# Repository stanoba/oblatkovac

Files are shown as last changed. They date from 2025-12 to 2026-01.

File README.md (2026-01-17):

# Electric Wafer Maker Controller (Oblátkovač)

Electric Wafer Maker Controller (Oblátkovač) runs on an Arduino Nano and is built with PlatformIO. It reads a thermistor, accepts input from a rotary encoder, and displays status on an SH1106/SSD1306 monochrome OLED using the U8g2 graphics library.

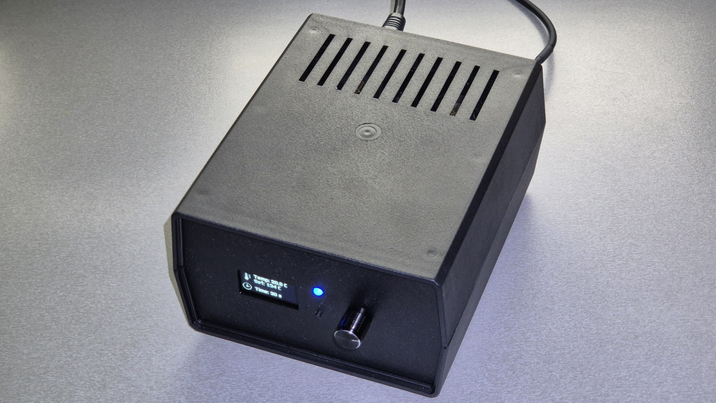
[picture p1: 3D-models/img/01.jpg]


## Software

The firmware source is in [Software](Software/) folder.

Build with PlatformIO, see `platformio.ini` for board environments.

## Bundled libraries

For reproducible builds this repo includes the following libraries under `Software/lib/`:

- `RotaryEncoder-1.5.3` — rotary encoder handling
- `ThermistorLibrary-1.0.6` — thermistor-to-temperature conversion
- `U8g2` — OLED display graphics
- `button-debounce-0.2.1` — simple button debounce helper

See `Software/lib/README` for details about each bundled library.

## Development tips

- If you change pin assignments, update `Software/src/pins.h` and rebuild for your target.
- Use PlatformIO's verbose build (`pio run -v`) to see full compiler/linker output when troubleshooting.
- To add a board environment, edit `platformio.ini` and add matching pin defines in the sketch as needed.

## Hardware

PCB design files are in the [Hardware](Hardware/) folder.

## Enclosure / 3D models

The electronics are housed in a [Z2AW enclosure](https://www.kradex.com.pl/product/enclosures_with_side_panels/z2a?lang=en). 3D-print models are in [3D-models](3D-models/).

## License

Project code is provided as-is. Third-party libraries retain their original licenses — see each library's `LICENSE` file in `Software/lib/`.

## Safety

**Warning:** this project involves mains and high-voltage circuitry. Working on or near high voltage can cause serious injury or death.

- **Disconnect power:** Always remove mains power and verify the circuit is de-energized before touching components.
- **Use PPE:** Wear appropriate personal protective equipment (insulating gloves, eye protection) when testing live systems.
- **Isolation:** Keep a safe distance from exposed conductors; use insulated tools and work on insulated surfaces.
- **Discharge capacitors:** Safely discharge capacitors before servicing; they can hold lethal charge after power removal.
- **One hand rule:** When possible, use the one-hand rule to avoid current passing through the chest.
- **Qualified personnel:** If you are not experienced with mains/high-voltage electronics, seek assistance from a qualified technician or electrician.
- **Work sober and focused:** Never work on high-voltage circuits when tired, impaired, or alone.

Follow local regulations and best practices for electrical safety. The authors are not responsible for damage or injury from misuse.

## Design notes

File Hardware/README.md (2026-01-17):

# Oblátkovač PCB (Work in progress)

The PCB for Oblátkovač (Electric Wafer Maker Controller) and schematic were designed using Autodesk EAGLE. Source EAGLE project files (schematic and board) are included in this folder.

- **Gerbers:** Manufacturing Gerber files are available in the [Hardware/gerber files/](Hardware/gerber%20files/) directory for PCB fabrication.
- **Libraries:** The EAGLE libraries used in the design are included in the [Hardware/libraries/](Hardware/libraries/) folder.
- **Notes:** Open the .sch and .brd files in Autodesk EAGLE. To regenerate Gerbers, use EAGLE's CAM processor and export an RS-274X Gerber set.
</br></br>

Eagle libraries Downloaded from:

- ArduinoNanoV30.lbr
    - https://github.com/psrobotics/eagle_lib
- Rembrandt Electronics - JST XH Connectors v1-0.lbr
    - https://github.com/yann-ygn/eagle-libraries/blob/master/Rembrandt%20Electronics%20-%20JST%20XH%20Connectors%20v1-0.lbr
    - https://www.diymodules.org/eagle-show-object?id=1012211612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
- 13oled.lbr
	- https://github.com/suhail-jr/1.3-OLED-Display-Module-Eagle-Library/
- mastrogippo.lbr
    - https://github.com/mastrogippo/MastroGippo-Eagle-library

## Schematic

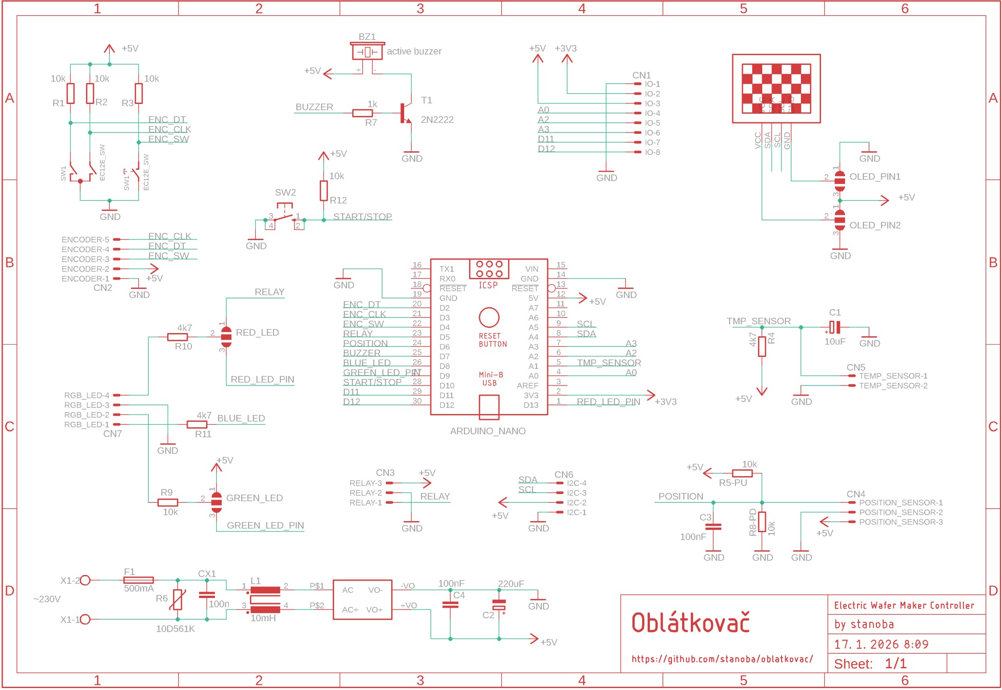
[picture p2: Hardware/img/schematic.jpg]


## PCB

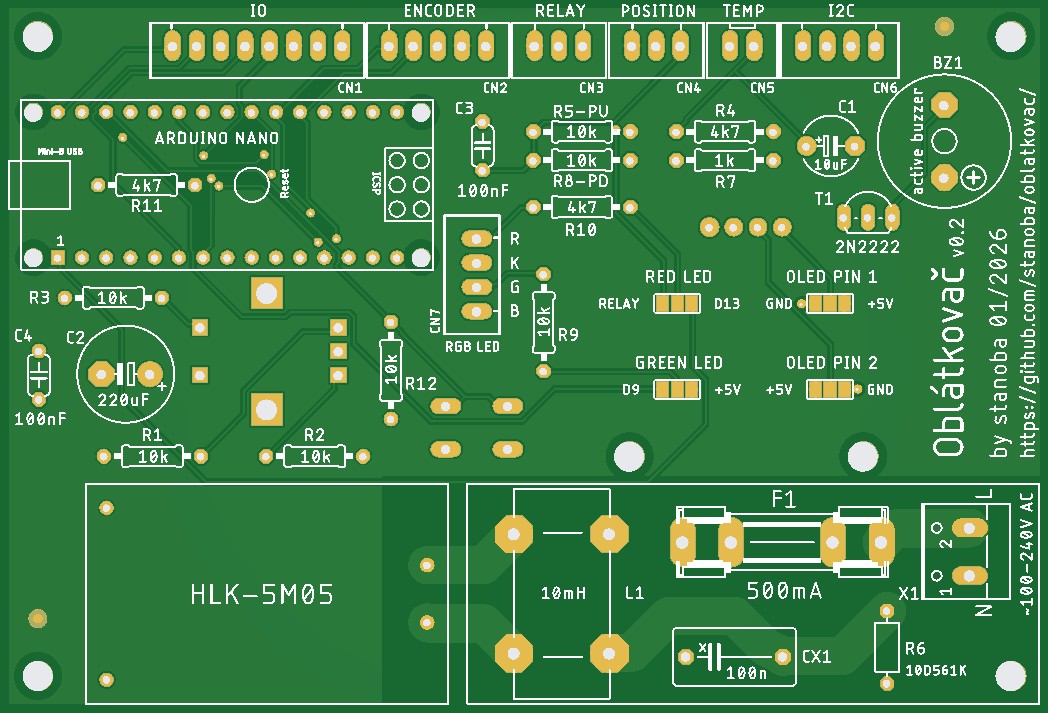
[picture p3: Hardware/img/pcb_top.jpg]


Front side:</br>
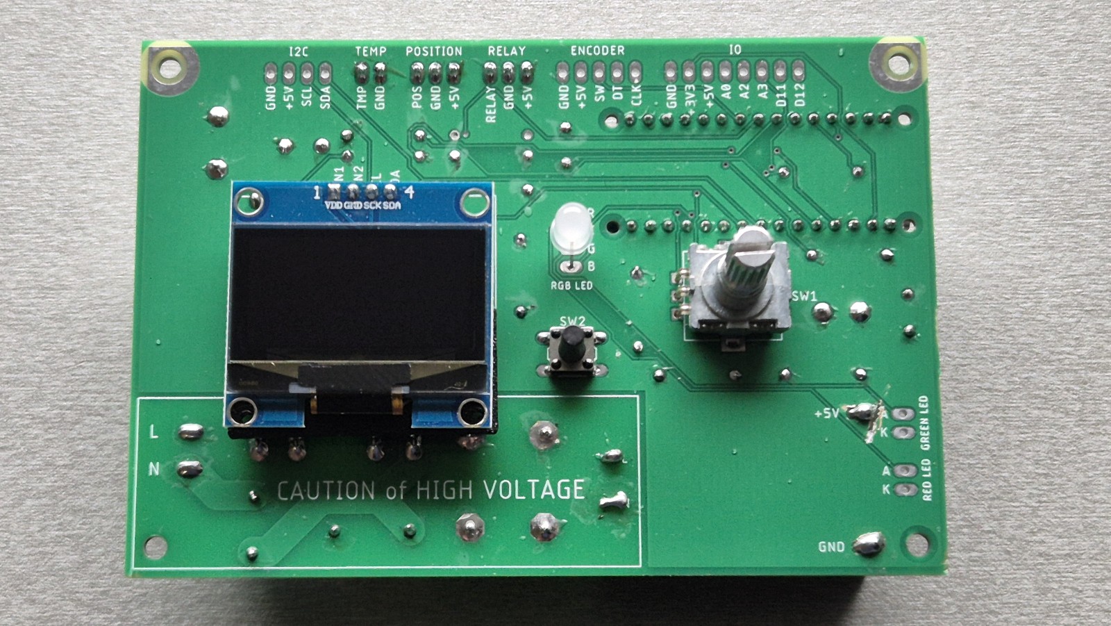
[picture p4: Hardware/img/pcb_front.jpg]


Back side:</br>
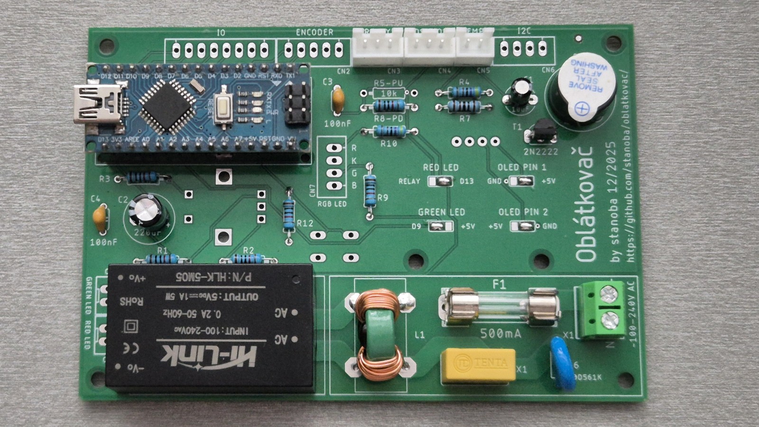
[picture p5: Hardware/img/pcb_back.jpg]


## Safety

**Warning:** this project involves mains and high-voltage circuitry. Working on or near high voltage can cause serious injury or death.

- **Disconnect power:** Always remove mains power and verify the circuit is de-energized before touching components.
- **Use PPE:** Wear appropriate personal protective equipment (insulating gloves, eye protection) when testing live systems.
- **Isolation:** Keep a safe distance from exposed conductors; use insulated tools and work on insulated surfaces.
- **Discharge capacitors:** Safely discharge capacitors before servicing; they can hold lethal charge after power removal.
- **One hand rule:** When possible, use the one-hand rule to avoid current passing through the chest.
- **Qualified personnel:** If you are not experienced with mains/high-voltage electronics, seek assistance from a qualified technician or electrician.
- **Work sober and focused:** Never work on high-voltage circuits when tired, impaired, or alone.

Follow local regulations and best practices for electrical safety. The authors are not responsible for damage or injury from misuse.

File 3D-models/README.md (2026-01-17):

# 3D Models and Enclosure

This folder contains the enclosure design and photos for the Oblátkovač electronics. The electronics fit into a [Z2AW enclosure](https://www.kradex.com.pl/product/enclosures_with_side_panels/z2a?lang=en), front and back panels (faces) are 3D-printed to match the PCB layout and connectors.

## Design source

- Original design created in SketchUp (file: `design.skp`).
- The provided SketchUp file is the editable source for the printed front/back panels and mounting features.

## Included files

- `design.skp` — SketchUp source project for the enclosure panels and mounting features.
- `front_pannel.stl` — Front panel with integrated mounting features for the PCB.
- `back_pannel.stl` — Back panel with cutouts and mounting openings for connectors.
- `heatsink_holder.stl` — Mounting bracket for the SSR (solid-state relay) heat sink.
- `oled_support.stl` — Support/bracket for the OLED display module.

## Printing & export notes

- Print the front and back panels in PETG (recommended) or ABS. PETG is easier to print and more dimensionally stable; ABS offers higher temperature resistance but may require an enclosed printer and additional post-processing.
- Typical print settings: 0.2 mm layer height, 15–30% infill, 2–4 perimeters. Use supports where needed for overhangs.
- Export to STL from SketchUp (SketchUp Pro or STL export plugin). Ensure model units are millimetres and scale is 1:1 before exporting.
- Check fit against the PCB and fasteners; consider printing a small test-fit section before full prints.

## Assembly

- Attach the assembled PCB to the front panel using the integrated mounting bosses.
- Install and secure all connectors into the back panel cutouts.
- Attach the SSR heat sink to its bracket and fasten securely.
- Complete wiring between the PCB, connectors and power components, following the schematic and safety guidelines.

## Final product



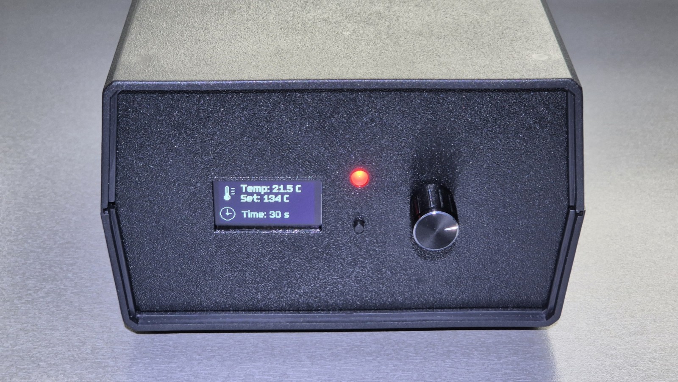
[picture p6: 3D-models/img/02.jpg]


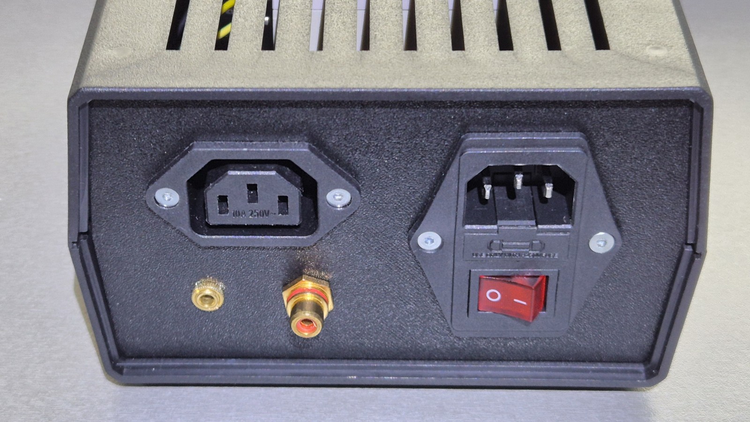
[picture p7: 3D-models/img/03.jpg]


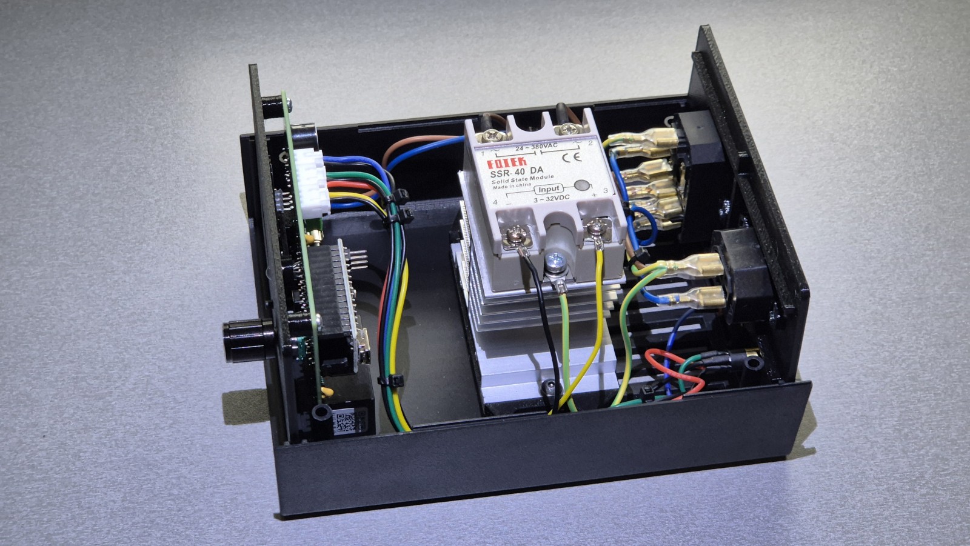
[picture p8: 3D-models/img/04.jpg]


## License

See the repository `LICENSE` at the project root for licensing terms.

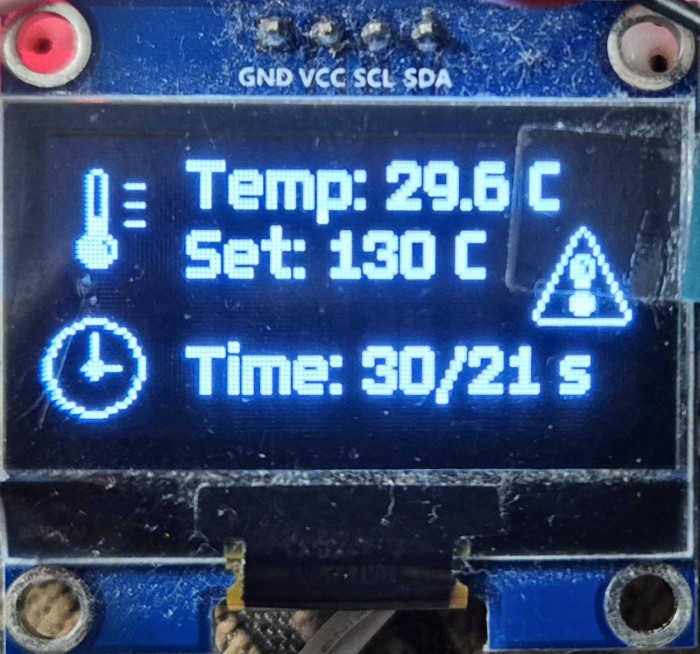
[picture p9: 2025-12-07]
Hardware/img/oled.jpg

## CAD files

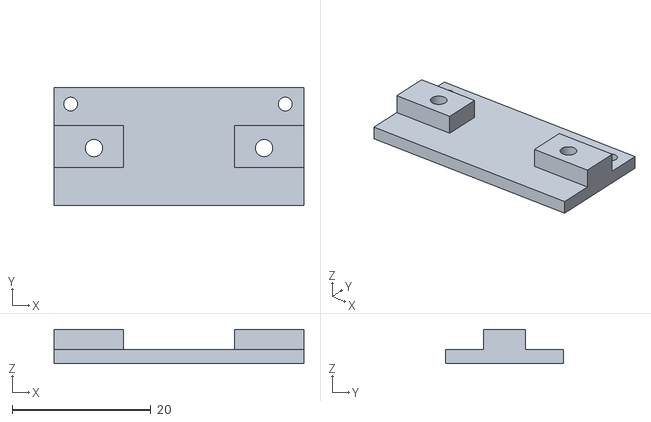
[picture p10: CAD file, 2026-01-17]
3D-models/oled_support.stl
36.0 x 17.0 x 4.90

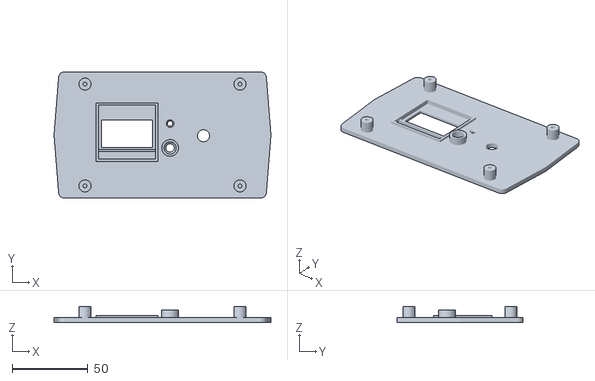
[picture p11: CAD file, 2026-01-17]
3D-models/front_pannel.stl
142.8 x 83.2 x 10.6

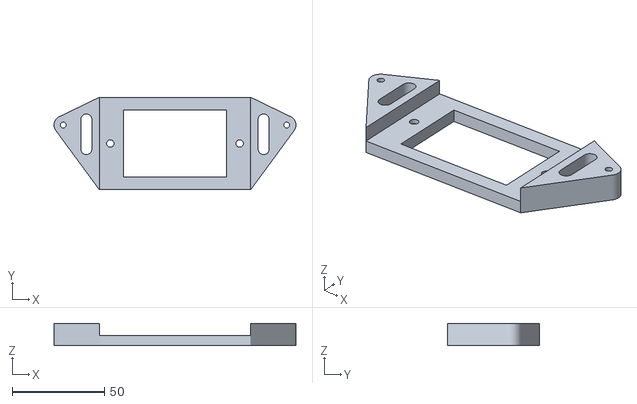
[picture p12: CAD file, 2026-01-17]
3D-models/heatsink_holder.stl
131.0 x 50.0 x 12.0

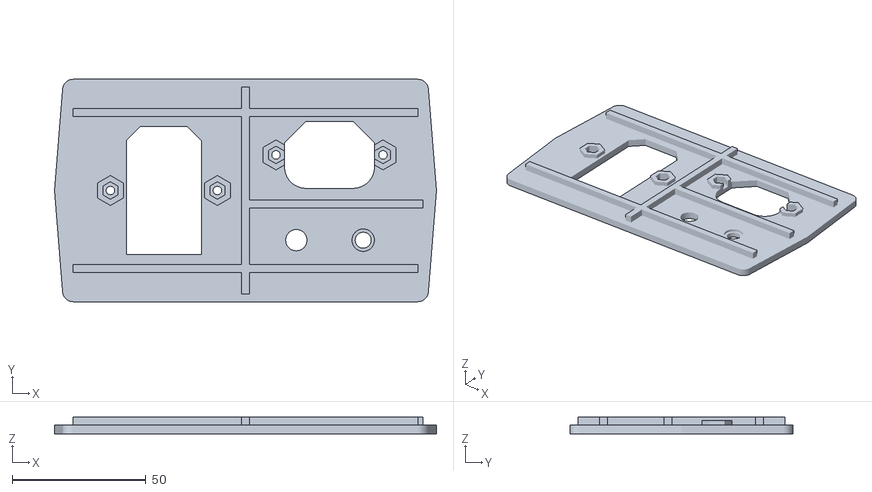
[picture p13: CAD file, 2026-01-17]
3D-models/back_pannel.stl
142.8 x 83.2 x 6.20

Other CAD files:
3D-models/design.skp

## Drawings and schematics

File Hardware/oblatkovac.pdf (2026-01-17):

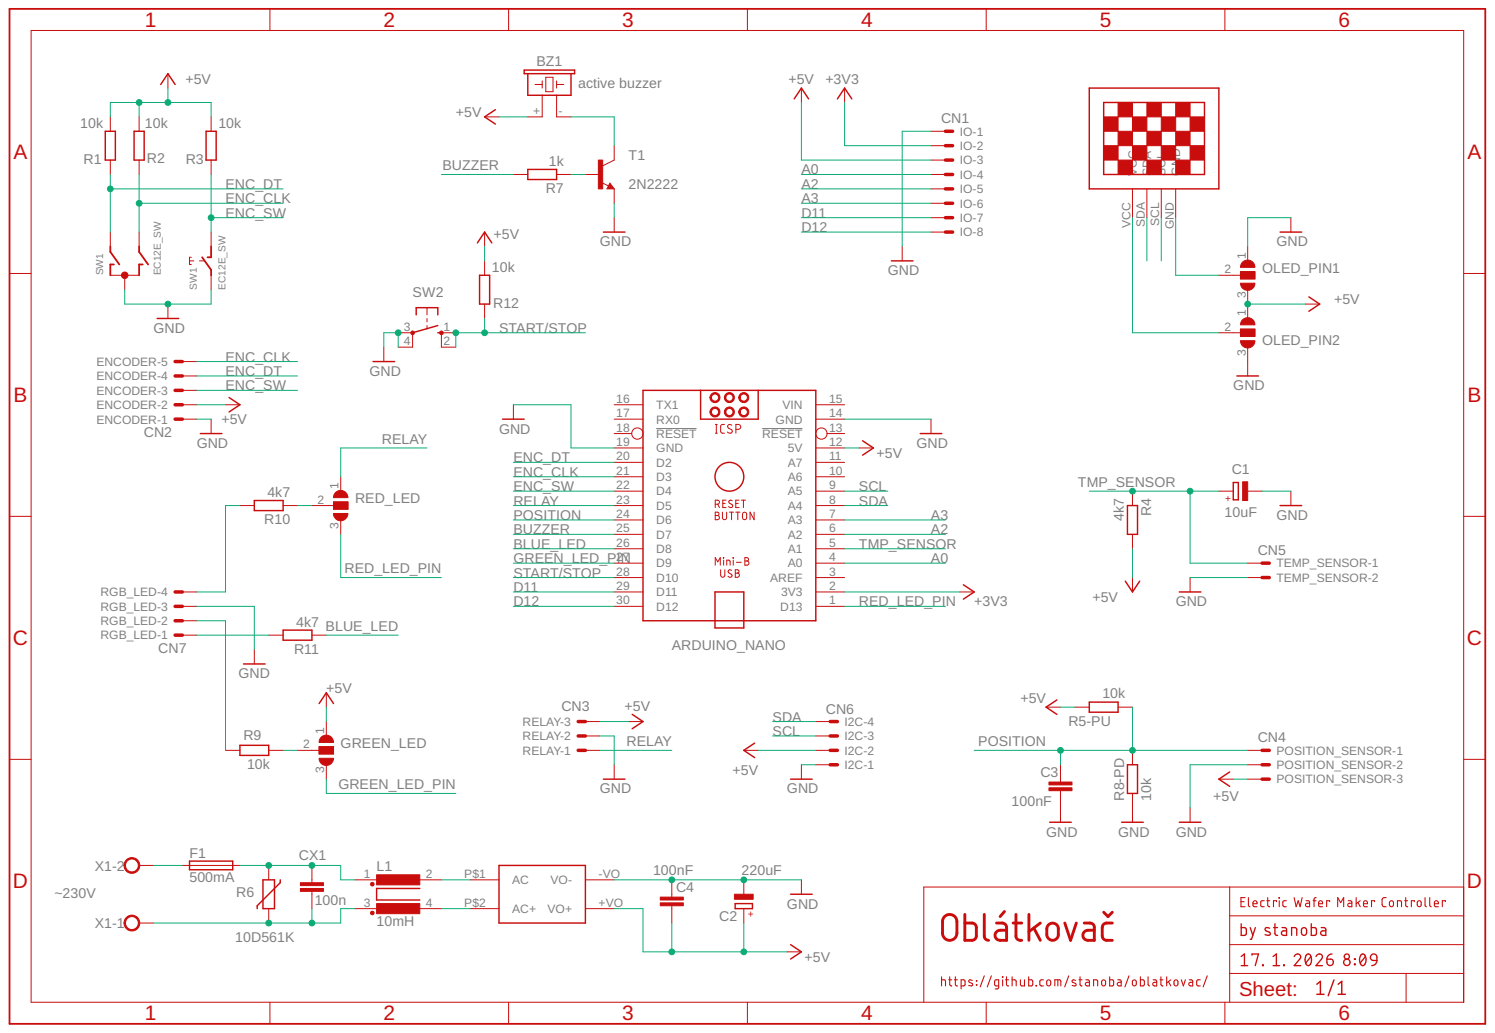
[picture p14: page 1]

ENCODER-1 ENCODER-2 ENCODER-3 ENCODER-4 ENCODER-5

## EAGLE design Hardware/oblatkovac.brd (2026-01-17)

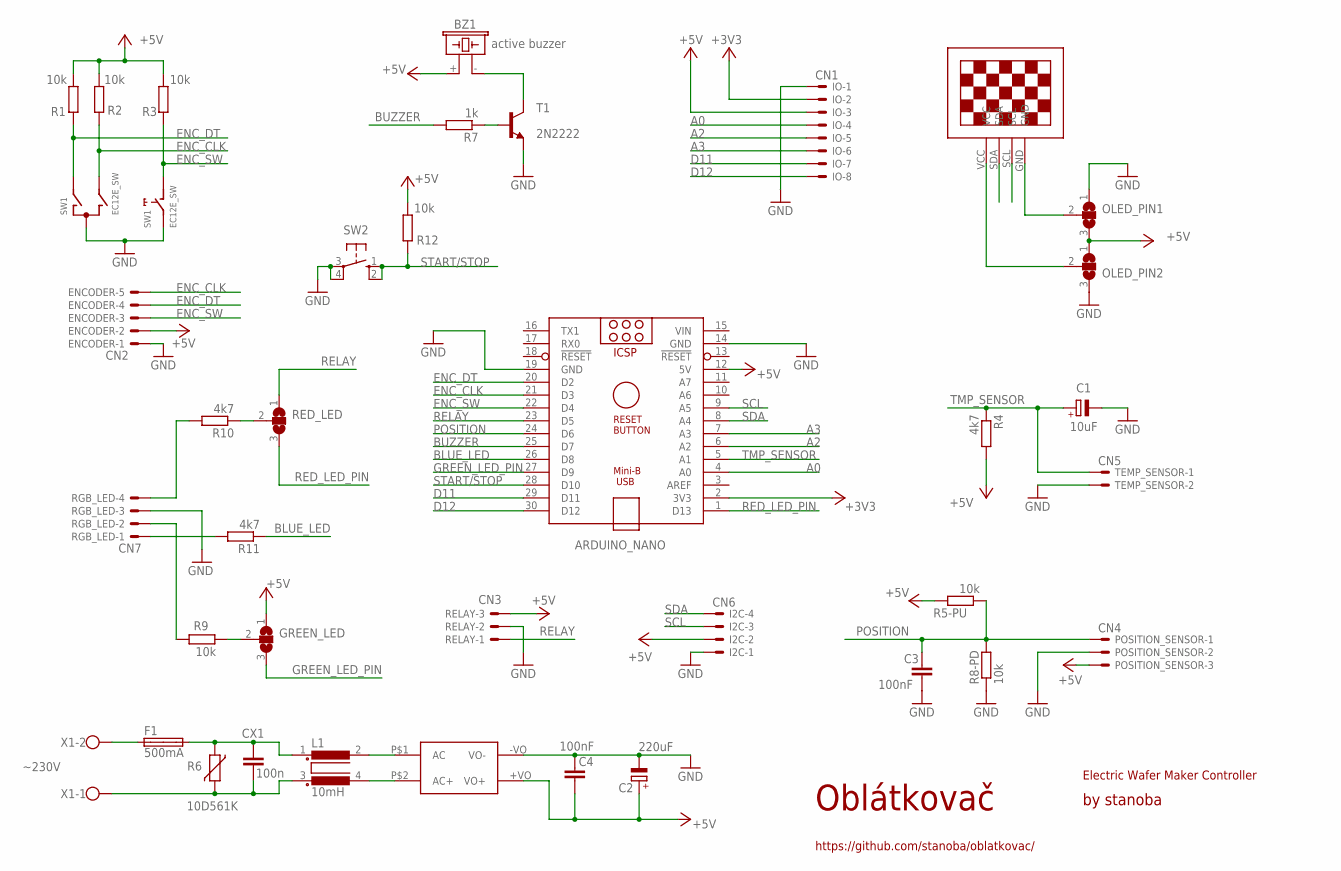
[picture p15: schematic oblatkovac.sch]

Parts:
ARDUINO_NANO: ARDUINO_NANO
BZ1: active buzzer; F/CM12P
C1: 10uF; E5-6
C2: 220uF; E5-10,5
C3, C4: 100nF; C050-024X044
CX1: 100n; XC10B6
ENCODER: CN2; JST-XH-05-PACKAGE-LONG-PAD
F1: 500mA; SHK20L
GREEN_LED: SJ2W; SJ_2
I2C: CN6; JST-XH-04-PACKAGE-LONG-PAD
IO: CN1; JST-XH-08-PACKAGE-LONG-PAD
L1: 10mH; B2
OLED_PIN1, OLED_PIN2: SJ2W; SJ_2
POSITION_SENSOR: CN4; JST-XH-03-PACKAGE-LONG-PAD
R1, R2, R3, R5-PU, R8-PD, R9, R12: 10k; 0207/10
R4, R10, R11: 4k7; 0207/10
R6: 10D561K; R-7,5
R7: 1k; 0207/10
RED_LED: SJ2W; SJ_2
RELAY: CN3; JST-XH-03-PACKAGE-LONG-PAD
RGB_LED: CN7; JST-XH-04-PACKAGE-LONG-PAD
SW1: EC12E_SW; ALPS_EC12E_SW
SW2: 10-XX; B3F-10XX
T1: 2N2222; TO92-EBC
TEMP_SENSOR: CN5; JST-XH-02-PACKAGE-LONG-PAD
U$1: 13"OLED13"OLED; 1.3"OLED
U$2: HLK-5M05
X1: ~230V; W237-102

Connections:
+3V3: ARDUINO_NANO.2 (3V3), IO.2
+5V: ARDUINO_NANO.12 (5V), BZ1.+ (1), C2.+, C4.2, ENCODER.2, GREEN_LED.1, I2C.2, IO.3, OLED_PIN1.3, OLED_PIN2.1, POSITION_SENSOR.3, R1.2, R2.2, R3.2, R4.2, R5-PU.2, R12.2, RELAY.3, U$2.+VO (VO+)
A0: ARDUINO_NANO.4 (A0), IO.4
A2: ARDUINO_NANO.6 (A2), IO.5
A3: ARDUINO_NANO.7 (A3), IO.6
BLUE_LED: ARDUINO_NANO.26 (D8), R11.1
BUZZER: ARDUINO_NANO.25 (D7), R7.2
D11: ARDUINO_NANO.29 (D11), IO.7
D12: ARDUINO_NANO.30 (D12), IO.8
ENC_CLK: ARDUINO_NANO.21 (D3), ENCODER.5, R2.1, SW1.B
ENC_DT: ARDUINO_NANO.20 (D2), ENCODER.4, R1.1, SW1.A
ENC_SW: ARDUINO_NANO.22 (D4), ENCODER.3, R3.1, SW1.D (1)
GND: ARDUINO_NANO.14 (GND), ARDUINO_NANO.19 (GND), C1.-, C2.-, C3.2, C4.1, ENCODER.1, I2C.1, IO.1, OLED_PIN1.1, OLED_PIN2.3, POSITION_SENSOR.2, R8-PD.1, RELAY.2, RGB_LED.3, SW1.C, SW1.E (2), SW2.3, SW2.4 (P1), T1.E, TEMP_SENSOR.2, U$2.-VO (VO-)
GREEN_LED_PIN: ARDUINO_NANO.27 (D9), GREEN_LED.3
LIVE_FUSED: F1.1A, X1.2
LIVE_FUSED2: CX1.1, F1.2A, L1.1, R6.1
LIVE_FUSED3: L1.2, U$2.P$1 (AC)
unnamed: R11.2, RGB_LED.1
unnamed: GREEN_LED.2, R9.2
unnamed: R9.1, RGB_LED.2
unnamed: R10.2, RGB_LED.4
unnamed: BZ1.- (2), T1.C
unnamed: R7.1, T1.B
unnamed: R10.1, RED_LED.2
NEUTRAL: CX1.2, L1.3, R6.2, X1.1
NEUTRAL2: L1.4, U$2.P$2 (AC+)
OLED_PIN1: OLED_PIN1.2, U$1.GND
OLED_PIN2: OLED_PIN2.2, U$1.VCC
POSITION: ARDUINO_NANO.24 (D6), C3.1, POSITION_SENSOR.1, R5-PU.1, R8-PD.2
RED_LED_PIN: ARDUINO_NANO.1 (D13), RED_LED.3
RELAY: ARDUINO_NANO.23 (D5), RED_LED.1, RELAY.1
SCL: ARDUINO_NANO.9 (A5), I2C.3, U$1.SCL
SDA: ARDUINO_NANO.8 (A4), I2C.4, U$1.SDA
START/STOP: ARDUINO_NANO.28 (D10), R12.1, SW2.1 (S), SW2.2 (S1)
TMP_SENSOR: ARDUINO_NANO.5 (A1), C1.+, R4.1, TEMP_SENSOR.1
VIN: ARDUINO_NANO.15 (VIN)

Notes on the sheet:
https://github.com/stanoba/oblatkovac/
by stanoba
Oblátkovač
Electric Wafer Maker Controller

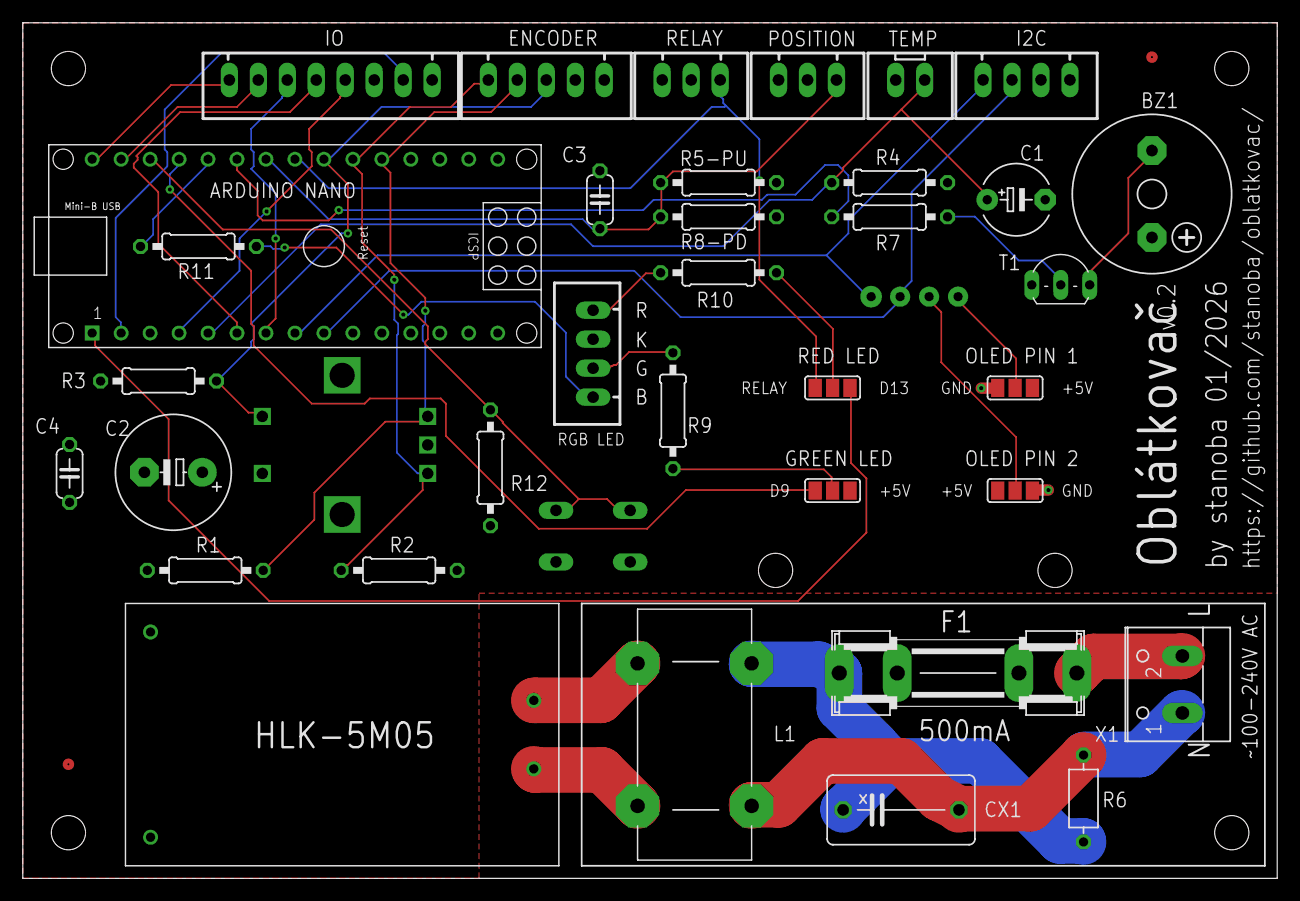
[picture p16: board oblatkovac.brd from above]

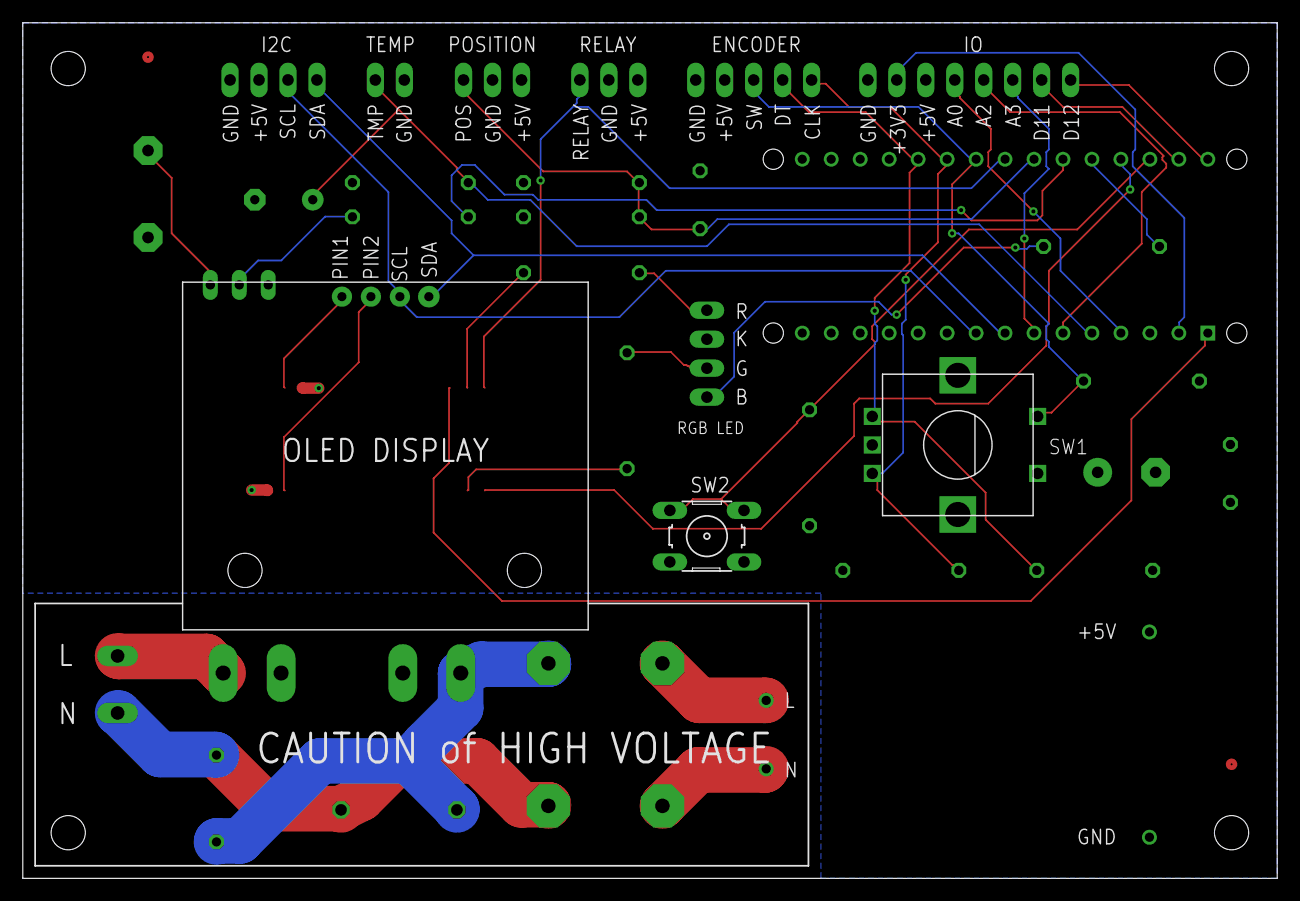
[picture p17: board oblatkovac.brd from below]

Board: 2 copper layers, 110.0 x 75.0 mm, 40 parts (3 on the bottom side), 35 nets.

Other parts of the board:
U$3, U$4: FIDUCIAL

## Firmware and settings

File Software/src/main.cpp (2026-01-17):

/*******************************************************************************
 * Electric Wafer Maker Controller (Oblátkovač)
 * GitHub: https://github.com/stanoba/oblatkovac
 * Date: 2025-12
 * Description: Main firmware — temperature sensing, heater control, UI,
 *              rotary encoders and buzzer logic.
 ******************************************************************************/

#include <Arduino.h>
#include <EEPROM.h>
#include <U8g2lib.h>
#include <Wire.h>
#include <RotaryEncoder.h>
#include <thermistor.h>
#include <debounce.h>
#include "pins.h"
#include "config.h"

// ###############################  Definitions  ###############################

// Use paged API (no full framebuffer) to save RAM on AVR
// Use the paged SH1106 constructor (mode 1) for HW I2C
U8G2_SH1106_128X64_NONAME_1_HW_I2C u8g2(U8G2_R0, U8X8_PIN_NONE, i2c_scl_pin, i2c_sda_pin);
thermistor therm1(thermistor_pin, 1); // Analog Pin which is connected to the 3950 temperature sensor
RotaryEncoder encoder1(encoder_clk_pin, encoder_dt_pin, RotaryEncoder::LatchMode::FOUR3); // Temperature encoder
RotaryEncoder encoder2(encoder_clk_pin, encoder_dt_pin, RotaryEncoder::LatchMode::FOUR3); // Time encoder

int target_temp = 0;
int time_countdown = 0;
int set_time = 0;
double temp = 0;
boolean heat_on = 1;
int rotary_steps = 1;
unsigned long previousTime = 0;
const unsigned long timeout = 500; //1000; // 1s in ms, update interval
boolean tick = 0;
boolean target_reached_once = 0; // Track whether we've already signaled reaching the target temperature
boolean buzzer_active = 0;       // Buzzer one-shot active flag and expiry time (ms)
unsigned long buzzer_off_time = 0;
int menu_positon = 1;
int lastPos1 = -1;
int lastPos2 = -1;
int run_state = 0;

// ################################  Functions  ################################

static void encoder_button_handler(uint8_t btnId, uint8_t btnState)
{
  if (btnState == BTN_PRESSED) {
    menu_positon++;
    if (menu_positon > 3) {
      menu_positon = 1;

      // Save settings values to EEPROM
      EEPROM.update(0, target_temp);
      EEPROM.update(1, set_time);

      Serial.println(F("Save settings values to EEPROM"));
      Serial.println("");
    }

#if DEBUG
    Serial.print(F("Menu: "));
    Serial.println(menu_positon);
    Serial.println("");
#endif
  }
}

static void start_stop_button_handler(uint8_t btnId, uint8_t btnState)
{
  if (btnState == BTN_PRESSED) {
    if (run_state == 0) {
      run_state = 1;
    }else{
      run_state = 0;
    }

#if DEBUG
    Serial.println(F("Button start/stop pressed"));
    Serial.print(F("Run state: "));
    Serial.println(run_state);
    Serial.println("");
#endif
  }
}

static Button encoder_button(0, encoder_button_handler);
static Button start_stop_button(1, start_stop_button_handler);

// ##################################  Setup  ##################################
void setup(void)
{
#if DEBUG
  Serial.begin(9600);
  Serial.println(F("Booting up..."));
  Serial.println("");
#endif

// EEPROM read settings
if (EEPROM.read(0) < min_temp || EEPROM.read(0) > max_temp) {
  target_temp = default_temp;
  #if DEBUG
    Serial.println(F("EEPROM temp address is empty"));
  #endif
} else {
  target_temp = EEPROM.read(0);
  #if DEBUG
    Serial.print(F("EEPROM temp value: "));
    Serial.println(target_temp);
    Serial.println("");
  #endif
}

if (EEPROM.read(1) < min_time || EEPROM.read(1) > max_time) { 
  set_time = default_time;
  time_countdown = set_time;
  #if DEBUG
    Serial.println(F("EEPROM time address is empty"));
  #endif
} else {
  set_time = EEPROM.read(1);
  time_countdown = set_time;
  #if DEBUG
    Serial.print(F("EEPROM time value: "));
    Serial.println(set_time);
    Serial.println("");
  #endif
}

  u8g2.begin(); // initialize the display

  // Initialize I2C/Wire with platform-specific pins when available.
#if defined(ESP8266) || defined(ESP32) || defined(CONFIG_IDF_TARGET_ESP32C3) || defined(ESP32_C3)
  Wire.begin(i2c_sda_pin, i2c_scl_pin);
#else
  Wire.begin();
#endif

  pinMode(relay_pin, OUTPUT);
  pinMode(buzzer_pin, OUTPUT);
  pinMode(led_green_pin, OUTPUT);
  pinMode(led_red_pin, OUTPUT);
  pinMode(led_blue_pin, OUTPUT);
  pinMode(encoder_sw_pin, INPUT);
  pinMode(reed_contact_pin, INPUT);

  // Indicate startup with blue LED
  digitalWrite(led_blue_pin, HIGH);

  encoder1.setPosition(target_temp);
  encoder2.setPosition(set_time);
}

static void pollButtons()
{
  encoder_button.update(digitalRead(encoder_sw_pin));
  start_stop_button.update(digitalRead(start_stop_button_pin));
}

// ##################################  Loop  ##################################
void loop(void)
{
  if (menu_positon == 2) {
    encoder1.tick();
  }

  if (menu_positon == 3) {
    encoder2.tick();
  }

  pollButtons(); // Poll your buttons every loop.

  int reed_contact = digitalRead(reed_contact_pin);

  // Timer for update interval (1 second)
  if (millis() >= (previousTime)) {
    previousTime = previousTime + timeout;
    tick = 1;
  } else {
    tick = 0;
  }

  if (reed_contact == LOW) {
    time_countdown = set_time;
  } else {
    if (time_countdown > 0 && target_reached_once == 1) {
      unsigned long currentTime = millis();
      static unsigned long lastCountdownTime = 0;
      if (currentTime - lastCountdownTime >= 1000) { // Decrease every second
        time_countdown--;
        lastCountdownTime = currentTime;
      }
    }
  }

  // Expire one-shot buzzer if time elapsed
  if (buzzer_active && (millis() >= buzzer_off_time)) {
    buzzer_active = 0;
  }

  // Buzzer priority: one-shot target-beep overrides countdown beep
  if (buzzer_active) {
    digitalWrite(buzzer_pin, HIGH);
  } else if (time_countdown == 1) {
    digitalWrite(buzzer_pin, HIGH);
  } else {
    digitalWrite(buzzer_pin, LOW);
  }

  // If it's time to update
  if (tick) {
    // read temperature
    temp = therm1.analog2temp();

    // Draw UI using paged API to avoid allocating a full framebuffer
    u8g2.firstPage();
    do {

      if (temp < 1){
        heat_on = 0;
        run_state = 0;
        digitalWrite(relay_pin, LOW);
        digitalWrite(led_green_pin, LOW);
        
        if (((previousTime / 500) % 2) == 0) {
          digitalWrite(led_blue_pin, HIGH);
          digitalWrite(led_red_pin, LOW);
        }else{
          digitalWrite(led_blue_pin, LOW);
          digitalWrite(led_red_pin, HIGH);
        }
          

        if (((previousTime / 500) % 2) == 0) {
          u8g2.setFont(u8g2_font_streamline_interface_essential_circle_triangle_t);
          u8g2.drawGlyph(55, 25, 0x33);
        }
          u8g2.setFont(u8g2_font_neuecraft_tr);
          u8g2.setCursor(10, 50);
          u8g2.print(F("No temp sensor!"));

      }else{

      // Icony
      // Thermometer
      u8g2.setFont(u8g2_font_streamline_weather_t);
      u8g2.drawGlyph(4, 28, 0x36);

      // Clock
      u8g2.setFont(u8g2_font_streamline_interface_essential_circle_triangle_t);
      u8g2.drawGlyph(0, 60, 0x36);

      // Blinking heater icon when ON
      // if (heat_on == 1) {
      //   if (((previousTime / 1000) % 2) == 0) {
      //     u8g2.setFont(u8g2_font_streamline_interface_essential_circle_triangle_t);
      //     u8g2.drawGlyph(105, 40, 0x33);
      //   }
      // }

      // Font text
      u8g2.setFont(u8g2_font_neuecraft_tr);

      // print temperature
      u8g2.setCursor(30, 15);
      u8g2.print(F("Temp: "));
      u8g2.print(temp, 1);
      u8g2.print(F(" °C"));



      if (run_state == 1) {
        // Turn heater OFF
        if (temp >= (target_temp + hysteresis) && heat_on == 1) {
          digitalWrite(relay_pin, LOW);
          heat_on = 0;
        }

        // Turn heater ON
        if (temp <= (target_temp - hysteresis) && run_state == 1) {
          digitalWrite(relay_pin, HIGH);
          heat_on = 1;
        }
      }else{
        // Ensure heater is OFF in stop mode
        digitalWrite(relay_pin, LOW);
        heat_on = 0;
        time_countdown = set_time;
      }

      if (run_state == 1 && heat_on == 1) {
        digitalWrite(led_red_pin, HIGH);
        digitalWrite(led_green_pin, LOW);
        digitalWrite(led_blue_pin, LOW);
      }else if (run_state == 1 && heat_on == 0) {
        digitalWrite(led_red_pin, LOW);
        digitalWrite(led_green_pin, HIGH);
        digitalWrite(led_blue_pin, LOW);
      }else{
        digitalWrite(led_red_pin, LOW);
        digitalWrite(led_green_pin, LOW);
        digitalWrite(led_blue_pin, HIGH);
      }


      // If target temperature is reached for the first time, beep buzzer for 1 second
      if (!target_reached_once && (temp >= target_temp) && run_state == 1) {
        target_reached_once = 1;
        buzzer_active = 1;
        buzzer_off_time = millis() + 1000; // 1 second
        digitalWrite(buzzer_pin, HIGH);     // immediate start of beep
      }

      u8g2.setCursor(30, 30);
      u8g2.print(F("Set: "));

      if (menu_positon == 2) {
        if (((previousTime / 500) % 2) == 0) {
          u8g2.print(target_temp);
          u8g2.print(F(" °C"));
        }
      } else {
        u8g2.print(target_temp);
        u8g2.print(F(" °C"));
      }

      u8g2.setCursor(30, 55);
      u8g2.print(F("Time: "));

      if (menu_positon == 3) {
        if (((previousTime / 500) % 2) == 0) {
          u8g2.print(set_time);
          u8g2.print(F(" s"));
        } else {
          u8g2.print(F("    "));
        }
      } else {
        u8g2.print(time_countdown);
        u8g2.print(F(" s"));
      }
     } // end temp==0 check
    } while (u8g2.nextPage());
  }

  // Rotary Encoder menu - temperature setting
  if (menu_positon == 2) {
    // get the current physical position and calc the logical position
    int newPos = encoder1.getPosition() * rotary_steps;

    if (newPos < min_temp) {
      encoder1.setPosition(min_temp / rotary_steps);
      newPos = min_temp;
    } else if (newPos > max_temp) {
      encoder1.setPosition(max_temp / rotary_steps);
      newPos = max_temp;
    }

    if (lastPos1 != newPos) {
      lastPos1 = newPos;
      target_temp = lastPos1;
    }
  }

  // Rotary Encoder menu - time setting
  if (menu_positon == 3) {
    // get the current physical position and calc the logical position
    int newPos2 = encoder2.getPosition() * rotary_steps;

    if (newPos2 < min_time) {
      encoder2.setPosition(min_time / rotary_steps);
      newPos2 = min_time;
    } else if (newPos2 > max_time) {
      encoder2.setPosition(max_time / rotary_steps);
      newPos2 = max_time;
    }

    if (lastPos2 != newPos2) {
      lastPos2 = newPos2;
      set_time = lastPos2;
    }
  }

  // Periodic global debug message every 5 seconds
#if DEBUG
  static unsigned long lastDebugTime = 0;
  const unsigned long debugInterval = 5000UL; // ms
  if (millis() - lastDebugTime >= debugInterval) {
    lastDebugTime = millis();
    Serial.println(F("=========== DEBUG ==========="));
    Serial.print(F("Curent Temp: "));
    Serial.println(temp, 1);
    Serial.print(F("Set Temp: "));
    Serial.println(target_temp);
    Serial.print(F("Heater: "));
    Serial.println(heat_on);
    Serial.print(F("Time Set: "));
    Serial.println(set_time);
    Serial.print(F("Time Left: "));
    Serial.println(time_countdown);
    Serial.print(F("Reed contact: "));
    Serial.println(reed_contact);
    Serial.print(F("Menu: "));
    Serial.println(menu_positon);
    Serial.println(F("==========================="));
    Serial.println("");
  }
#endif
}
// End

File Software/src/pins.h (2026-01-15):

// Pin definitions
  int encoder_dt_pin = 3;
  int encoder_clk_pin = 2;
  int encoder_sw_pin = 4;
  int relay_pin = 5;
  int reed_contact_pin = 6;
  int buzzer_pin = 7;
  int thermistor_pin = A1;
  int led_green_pin = 9;
  int led_red_pin = 13;
  int led_blue_pin = 8;
  int start_stop_button_pin = 10;
  int i2c_sda_pin = A4;
  int i2c_scl_pin = A5;

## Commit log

2025-12-07 - Improve platform pin definitions - Add time counter - Add OLED image to README
2025-12-08 Refactor encoder variable names for clarity and update comments
2025-12-21 Add Hardware folder
    [oblatkovac.brd, oblatkovac.sch]
2026-01-15 Update code according new PCB design
2026-01-15 Fix logical operators for clarity and consistency in heater control logic
    [main.cpp]
2026-01-16 Implement EEPROM storage for target temperature and countdown time
2026-01-17 - Improved temperature sensing, heater control, and UI. - Integrated EEPROM for saving settings. - Configured button handlers for menu navigation and start/stop functionality. - Established pin defin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
    [back_pannel.stl, design.skp, front_pannel.stl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]
2026-01-17 Update README.md and add new schematic PDF to Hardware documentation
2026-01-17 Refactor README.md to improve formatting of PCB images section
